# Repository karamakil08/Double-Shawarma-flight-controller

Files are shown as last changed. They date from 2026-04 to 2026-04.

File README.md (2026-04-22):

🚀 Double Shawarma: High-Performance Micro Drone
Double Shawarma is a custom-engineered, ultra-lightweight micro drone built on the ESP32-C3 architecture. Designed for agility and durability, this project pushes the limits of 1S-powered flight using 8.5mm coreless motors and a bespoke 3D-printed chassis optimized for maximum structural rigidity.

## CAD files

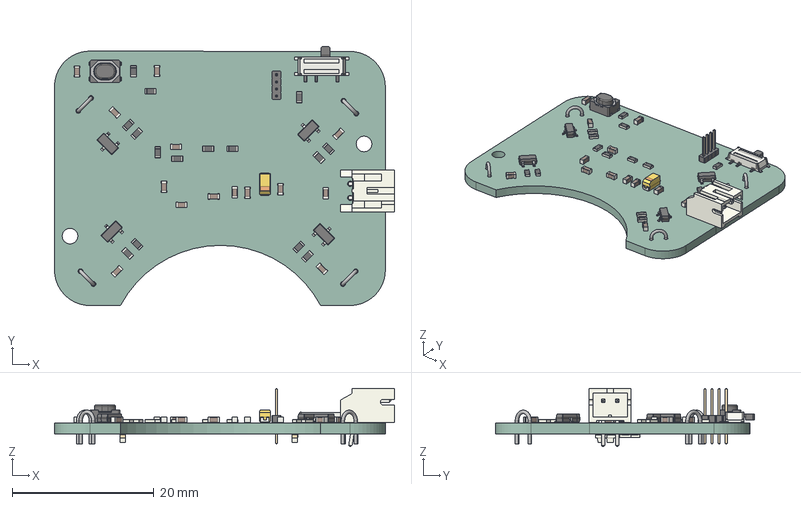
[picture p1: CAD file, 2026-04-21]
PCB/delikli.step
48.0 x 36.6 x 8.25 mm
R_0603_1608Metric x 17
JST_PH_S2B-PH-K_1x02_P2.00mm_Horizontal
SOT-23 x 4
SW_SPDT_PCM12
C_0603_1608Metric x 14
TestPoint_Bridge_Pitch2.54mm_Drill0.7mm x 4
SW_SPST_PTS810
CP_EIA-3216-18_Kemet-A
PinHeader_1x04_P1.00mm_Vertical
LED_0603_1608Metric x 2
Dobule shawarma PCB_PCB

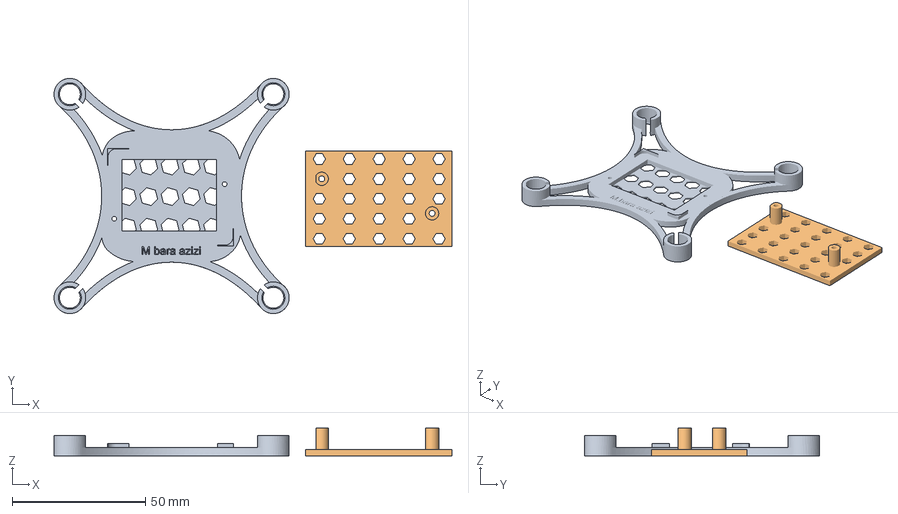
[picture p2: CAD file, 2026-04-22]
ready to print_1.3mf
149.6 x 88.4 x 10.4 mm

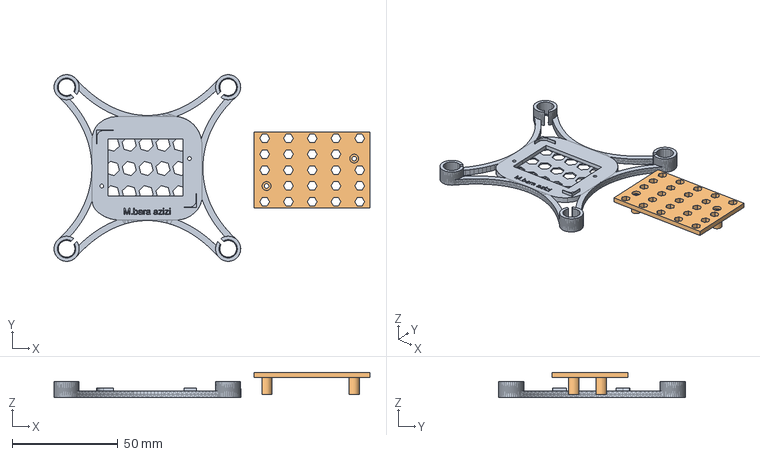
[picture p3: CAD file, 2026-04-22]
final_22_04.step
149.6 x 88.4 x 12.0 mm

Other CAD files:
FRAME.gcode.3mf

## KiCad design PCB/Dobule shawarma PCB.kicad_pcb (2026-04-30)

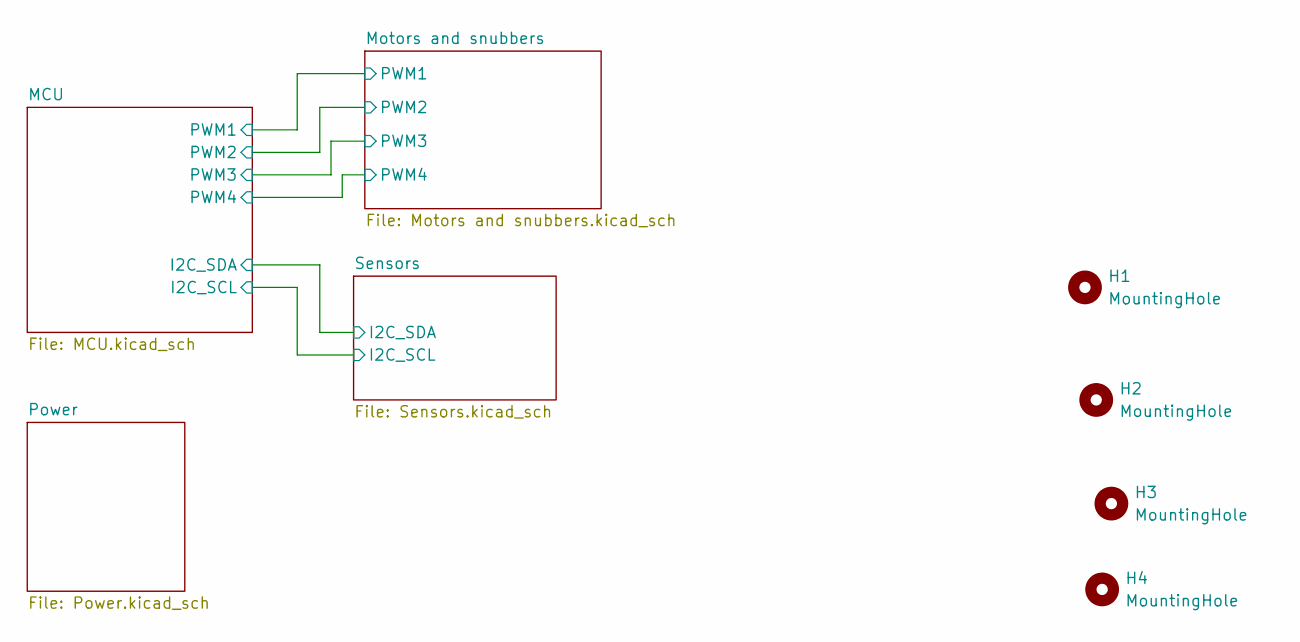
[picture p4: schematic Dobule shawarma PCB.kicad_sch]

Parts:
H1, H2, H3, H4: MountingHole; MountingHole_2.2mm_M2_Pad_Via

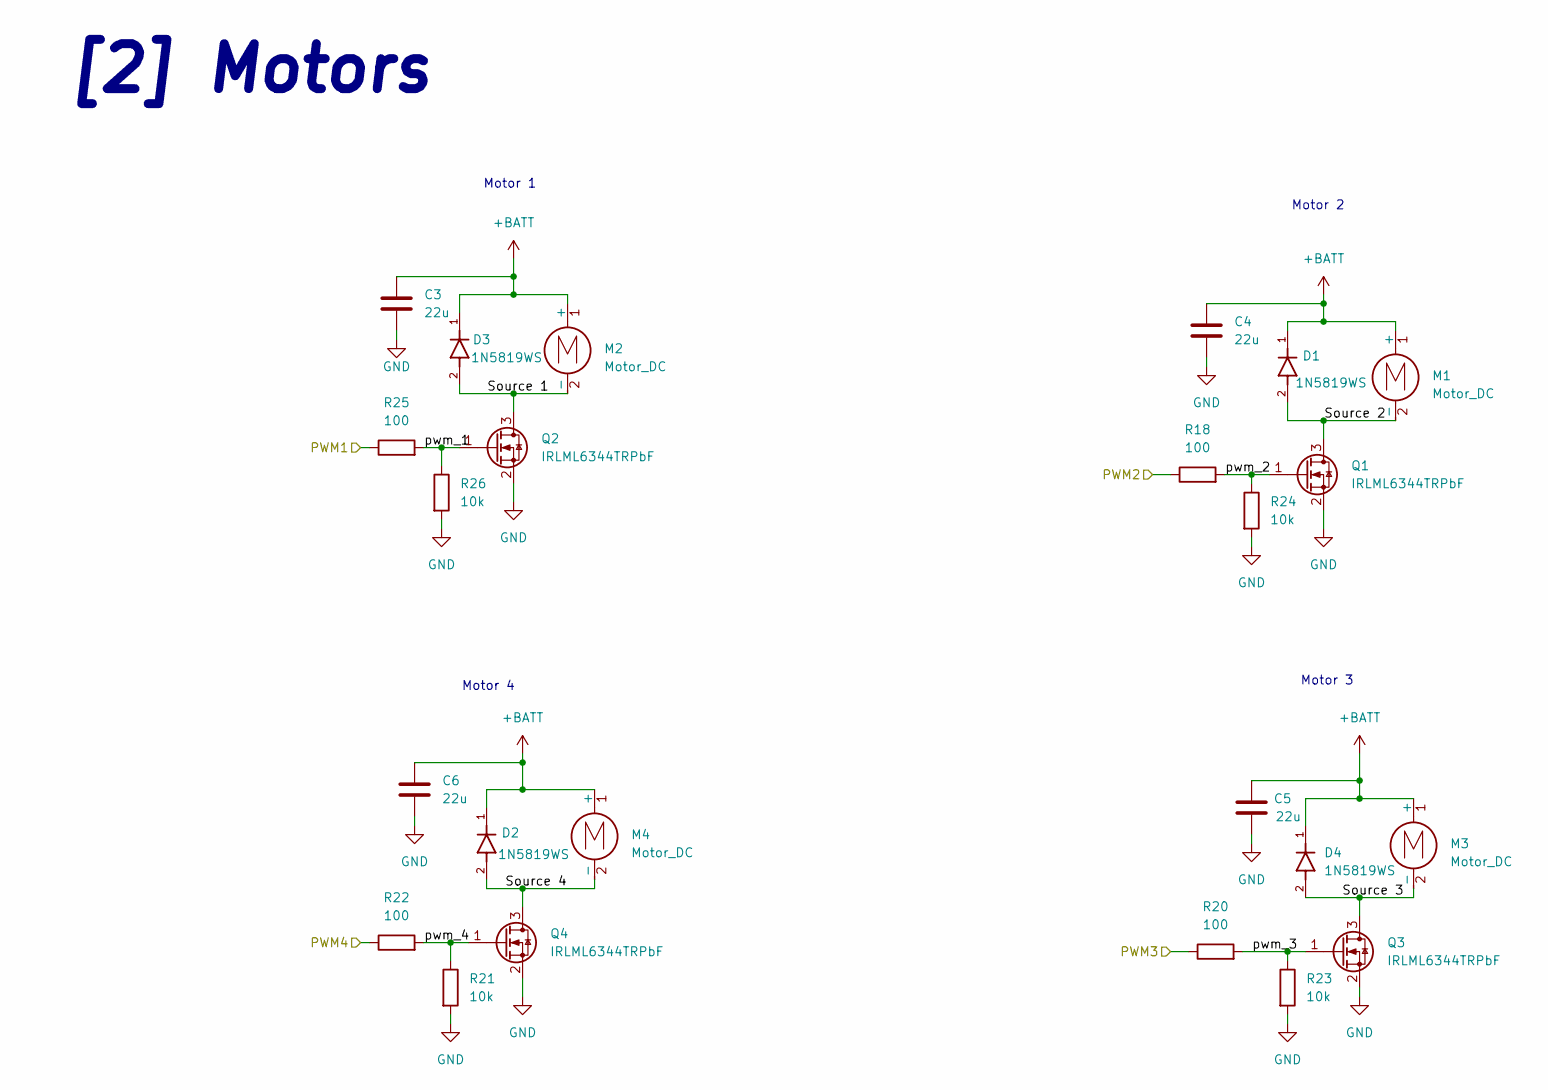
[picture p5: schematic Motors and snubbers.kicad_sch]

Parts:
C3, C4, C5, C6: 22u; C_0603_1608Metric_Pad1.08x0.95mm_HandSolder
D1, D2, D3, D4: 1N5819WS; CR_SOD323_MCC; PARTREV G
M1, M2, M3, M4: Motor_DC; TestPoint_Bridge_Pitch2.54mm_Drill0.7mm
Q1, Q2, Q3, Q4: IRLML6344TRPbF; SOT-23
R18, R20, R22, R25: 100; R_0603_1608Metric_Pad0.98x0.95mm_HandSolder
R21, R23, R24, R26: 10k; R_0603_1608Metric_Pad0.98x0.95mm_HandSolder

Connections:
+BATT: C3.2, C4.2, C5.2, C6.2, D1.1, D2.1, D3.1, D4.1, M1.1 (+), M2.1 (+), M3.1 (+), M4.1 (+); also elsewhere on the board
/MCU/PWM1: R25.1; also elsewhere on the board
/MCU/PWM2: R18.1; also elsewhere on the board
/MCU/PWM3: R20.1; also elsewhere on the board
/MCU/PWM4: R22.1; also elsewhere on the board
/Motors and snubbers/Source 1: D3.2, M2.2 (-), Q2.3 (D)
/Motors and snubbers/Source 2: D1.2, M1.2 (-), Q1.3 (D)
/Motors and snubbers/Source 3: D4.2, M3.2 (-), Q3.3 (D)
/Motors and snubbers/Source 4: D2.2, M4.2 (-), Q4.3 (D)
/Motors and snubbers/pwm_1: Q2.1 (G), R25.2, R26.1
/Motors and snubbers/pwm_2: Q1.1 (G), R18.2, R24.1
/Motors and snubbers/pwm_3: Q3.1 (G), R20.2, R23.1
/Motors and snubbers/pwm_4: Q4.1 (G), R21.1, R22.2
GND: C3.1, C4.1, C5.1, C6.1, Q1.2 (S), Q2.2 (S), Q3.2 (S), Q4.2 (S), R21.2, R23.2, R24.2, R26.2; also elsewhere on the board

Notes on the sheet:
Motor 3
Motor 2
Motor 1
[2] Motors
Motor 4

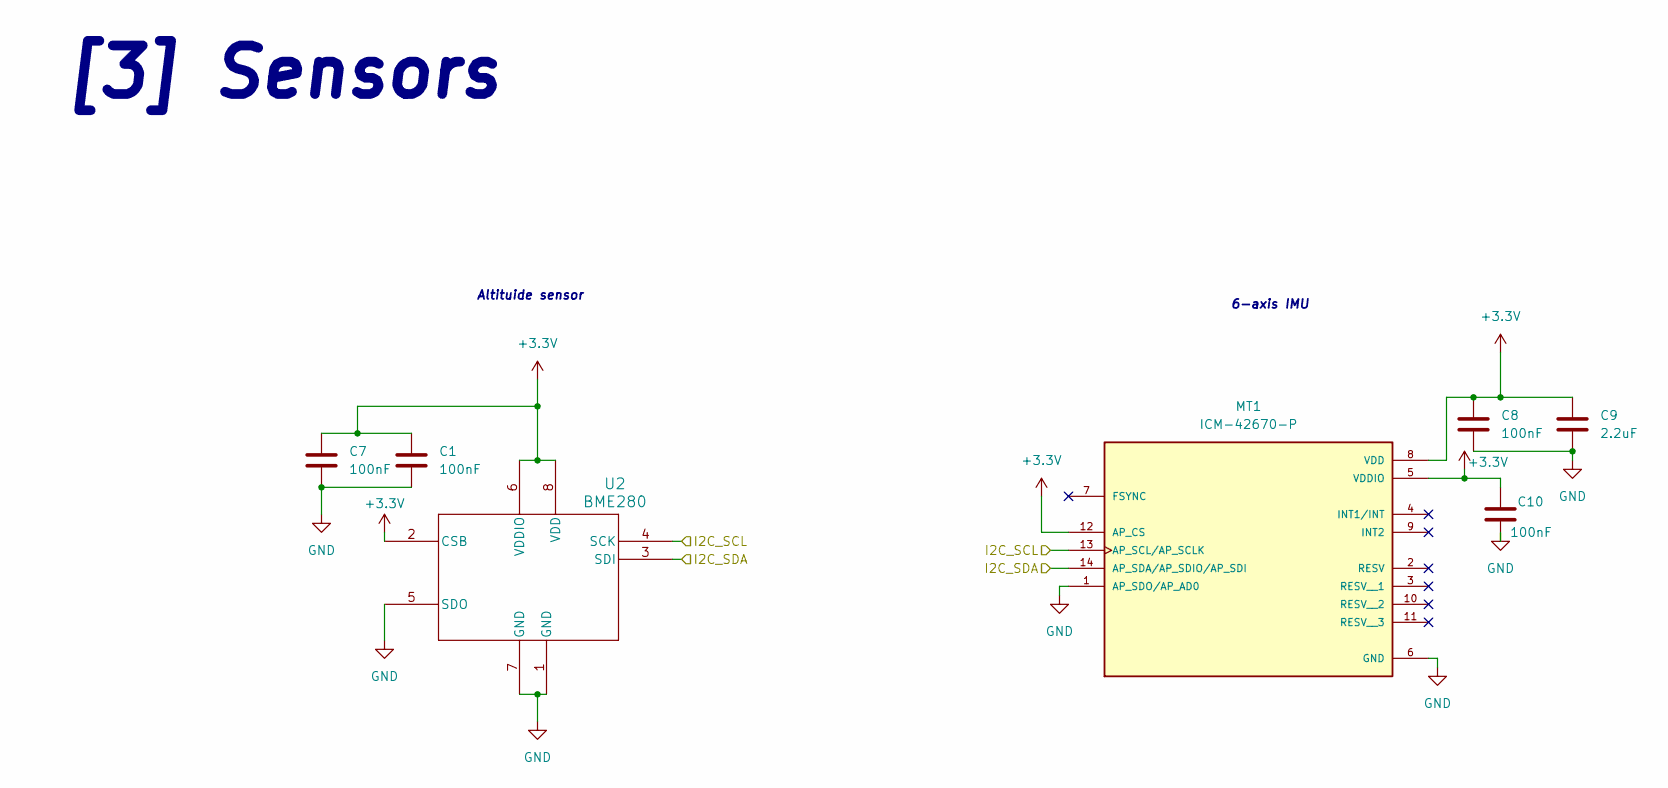
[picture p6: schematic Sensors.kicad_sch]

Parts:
C1, C7, C8, C10: 100nF; C_0603_1608Metric_Pad1.08x0.95mm_HandSolder
C9: 2.2uF; C_0603_1608Metric_Pad1.08x0.95mm_HandSolder
MT1: ICM-42670-P; XDCR_ICM-42670-P; PARTREV 1.1
U2: BME280; DFN8_0p65_2p5SQ_BOS

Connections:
+3.3V: C1.1, C7.1, C8.1, C9.1, C10.1, MT1.5 (VDDIO), MT1.8 (VDD), MT1.12 (AP_CS), U2.2 (CSB), U2.6 (VDDIO), U2.8 (VDD); also elsewhere on the board
/MCU/I2C_SCL: MT1.13 (AP_SCL/AP_SCLK), U2.4 (SCK); also elsewhere on the board
/MCU/I2C_SDA: MT1.14 (AP_SDA/AP_SDIO/AP_SDI), U2.3 (SDI); also elsewhere on the board
GND: C1.2, C7.2, C8.2, C9.2, C10.2, MT1.1 (AP_SDO/AP_AD0), MT1.6 (GND), U2.1 (GND), U2.5 (SDO), U2.7 (GND); also elsewhere on the board

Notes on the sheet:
6-axis IMU
Altituide sensor
[3] Sensors

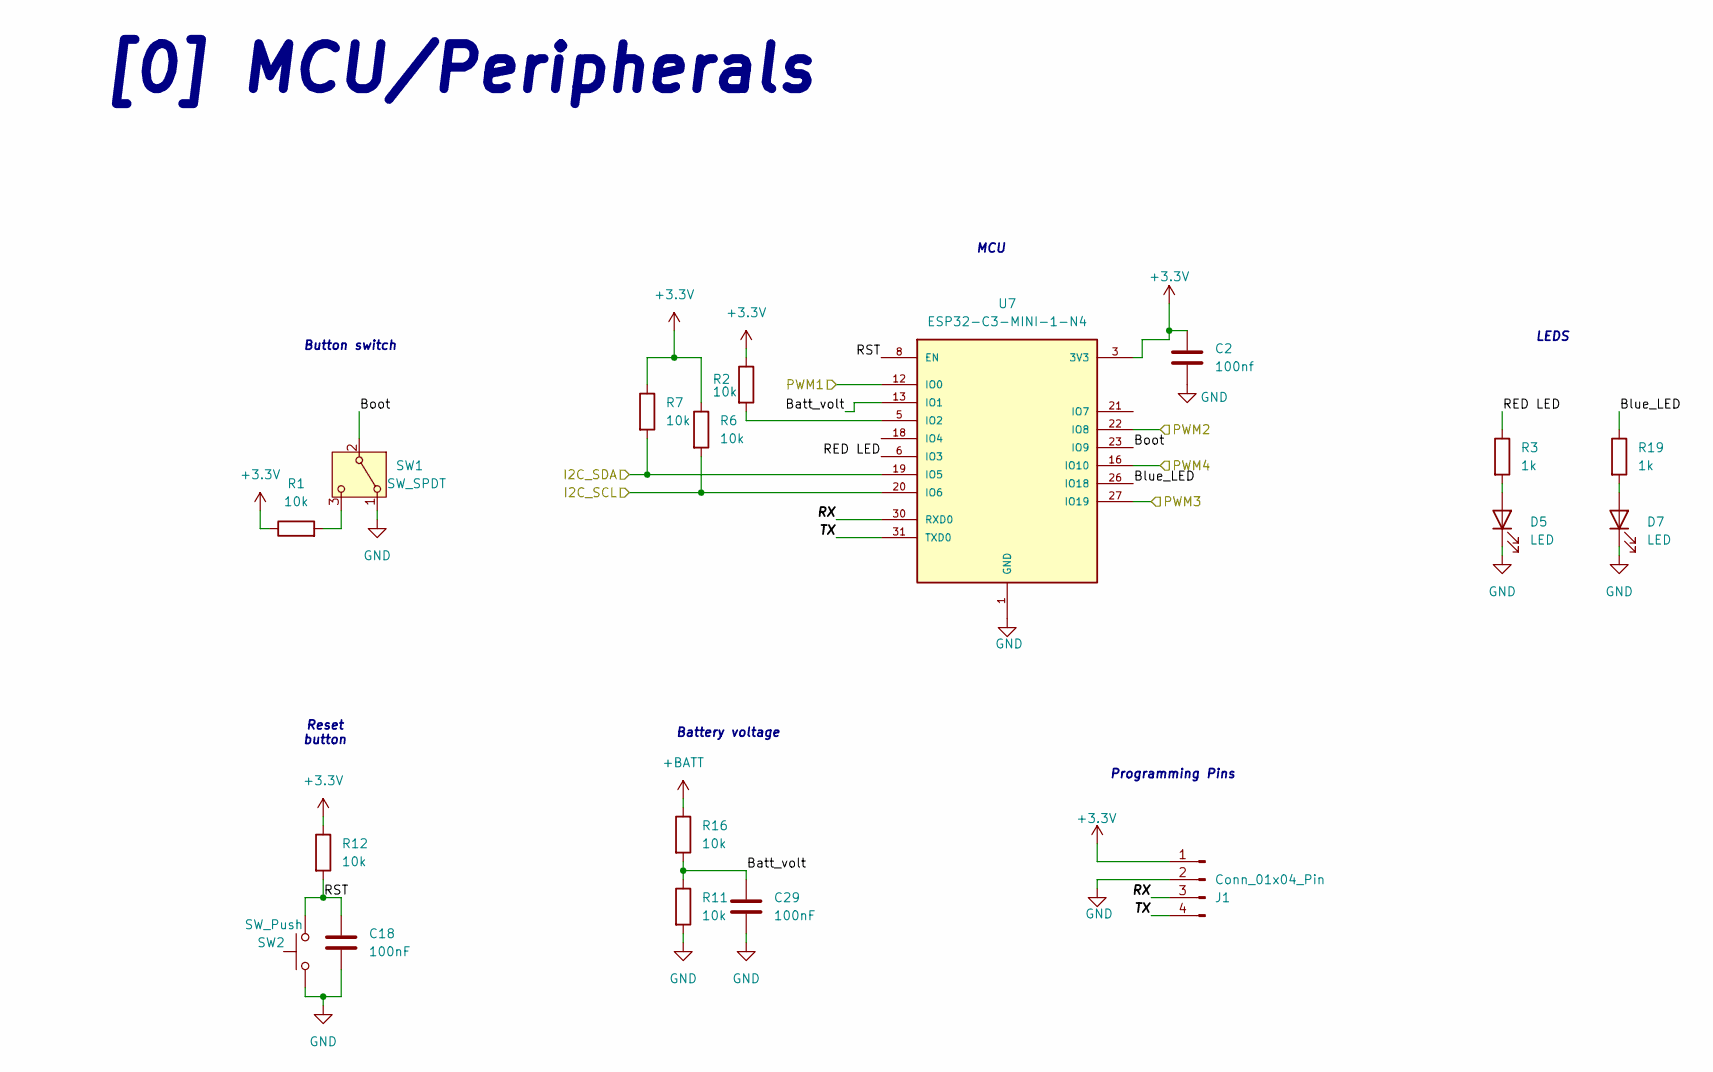
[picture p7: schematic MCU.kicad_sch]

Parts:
C2: 100nf; C_0603_1608Metric_Pad1.08x0.95mm_HandSolder
C18, C29: 100nF; C_0603_1608Metric_Pad1.08x0.95mm_HandSolder
D5, D7: LED; LED_0603_1608Metric_Pad1.05x0.95mm_HandSolder
J1: Conn_01x04_Pin; PinHeader_1x04_P1.00mm_Vertical
R1, R2: 10k; R_0603_1608Metric
R3, R19: 1k; R_0603_1608Metric_Pad0.98x0.95mm_HandSolder
R6, R7, R11, R12, R16: 10k; R_0603_1608Metric_Pad0.98x0.95mm_HandSolder
SW1: SW_SPDT; SW_SPDT_PCM12
SW2: SW_Push; SW_SPST_PTS810
U7: ESP32-C3-MINI-1-N4; XCVR_ESP32-C3-MINI-1-N4; PARTREV v1.0

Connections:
+3.3V: C2.1, J1.1, R1.1, R2.1, R6.1, R7.1, R12.1, U7.3 (3V3); also elsewhere on the board
+BATT: R16.1; also elsewhere on the board
/MCU/Batt_volt: C29.1, R11.1, R16.2, U7.13 (IO1)
/MCU/Blue_LED: R19.1, U7.26 (IO18)
/MCU/Boot: SW1.2 (B), U7.23 (IO9)
/MCU/I2C_SCL: R6.2, U7.20 (IO6); also elsewhere on the board
/MCU/I2C_SDA: R7.2, U7.19 (IO5); also elsewhere on the board
/MCU/PWM1: U7.12 (IO0); also elsewhere on the board
/MCU/PWM2: U7.22 (IO8); also elsewhere on the board
/MCU/PWM3: U7.27 (IO19); also elsewhere on the board
/MCU/PWM4: U7.16 (IO10); also elsewhere on the board
/MCU/RED LED: R3.1, U7.6 (IO3)
/MCU/RST: C18.1, R12.2, SW2.2, U7.8 (EN)
/MCU/RX: J1.3, U7.30 (RXD0)
/MCU/TX: J1.4, U7.31 (TXD0)
GND: C2.2, C18.2, C29.2, D5.1 (K), D7.1 (K), J1.2, R11.2, SW1.1 (A), SW2.1, U7.1 (GND), U7.2 (GND__1), U7.11 (GND__2), U7.14 (GND__3), U7.36 (GND__4), U7.37 (GND__5), U7.38 (GND__6), U7.39 (GND__7), U7.40 (GND__8), U7.41 (GND__9), U7.42 (GND__10), U7.43 (GND__11), U7.44 (GND__12), U7.45 (GND__13), U7.46 (GND__14), U7.47 (GND__15), U7.48 (GND__16), U7.49_1 (GND__17), U7.49_2 (GND__18), U7.49_3 (GND__19), U7.49_4 (GND__20), U7.49_5 (GND__21), U7.49_6 (GND__22), U7.49_7 (GND__23), U7.49_8 (GND__24), U7.49_9 (GND__25), U7.50 (GND__26), U7.51 (GND__27), U7.52 (GND__28), U7.53 (GND__29); also elsewhere on the board
unnamed: D5.2 (A), R3.2
unnamed: D7.2 (A), R19.2
unnamed: R1.2, SW1.3 (C)
unnamed: R2.2, U7.5 (IO2)

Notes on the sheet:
MCU
LEDS
Reset button
[0] MCU/Peripherals
Button switch
Programming Pins
Battery voltage

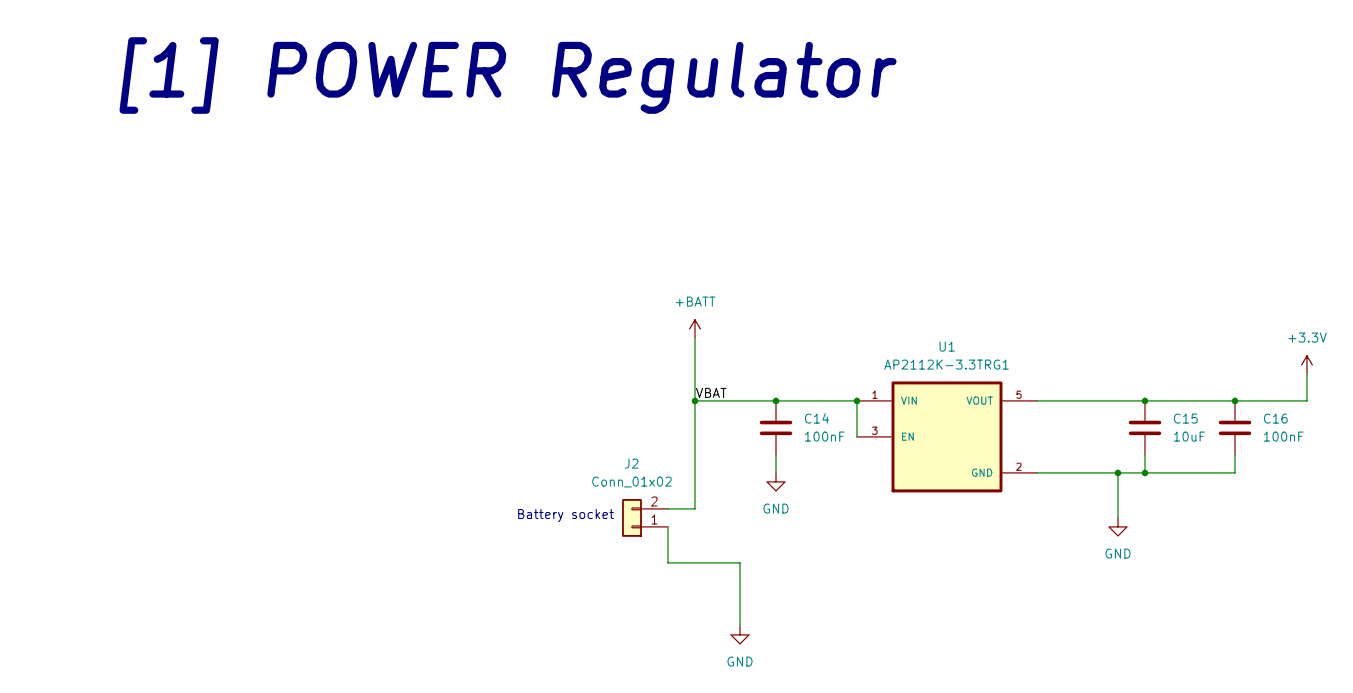
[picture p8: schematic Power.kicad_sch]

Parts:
C14, C16: 100nF; C_0603_1608Metric_Pad1.08x0.95mm_HandSolder
C15: 10uF; CP_EIA-3216-18_Kemet-A_HandSolder
J2: Conn_01x02; JST_PH_S2B-PH-K_1x02_P2.00mm_Horizontal
U1: AP2112K-3.3TRG1; SOT95P285X140-5N; PARTREV 2-2

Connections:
+3.3V: C15.1, C16.1, U1.5 (VOUT); also elsewhere on the board
+BATT: C14.1, J2.2, U1.1 (VIN), U1.3 (EN); also elsewhere on the board
GND: C14.2, C15.2, C16.2, J2.1, U1.2 (GND); also elsewhere on the board

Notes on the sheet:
[1] POWER Regulator
Battery socket

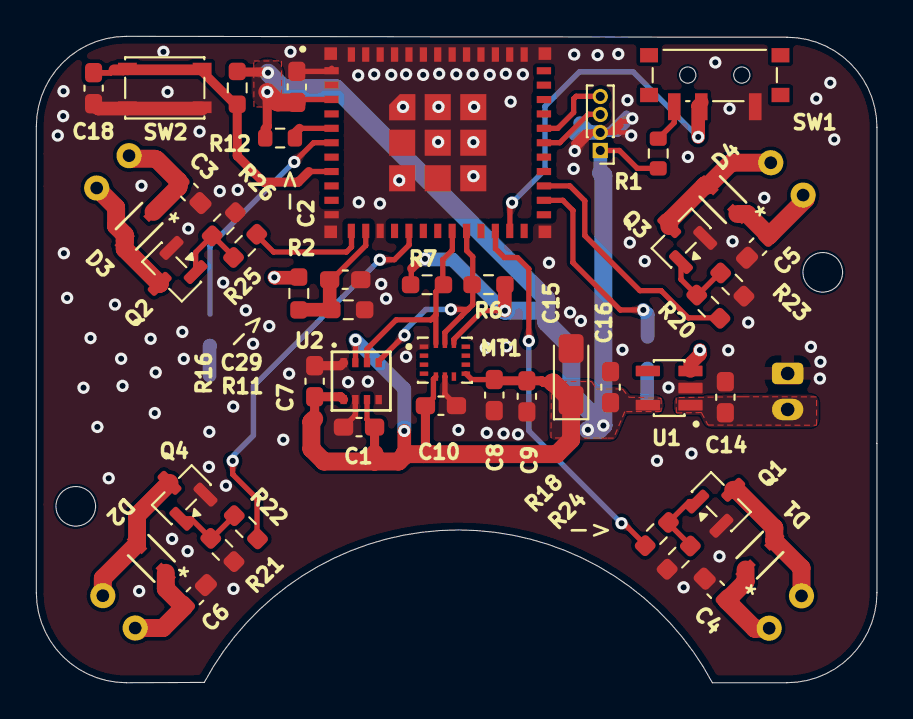
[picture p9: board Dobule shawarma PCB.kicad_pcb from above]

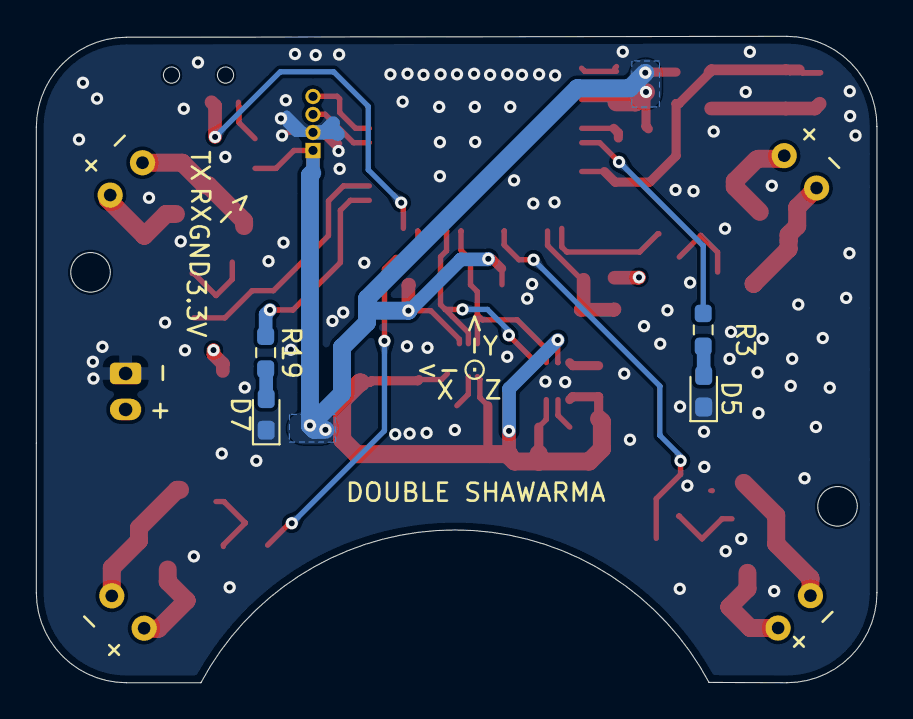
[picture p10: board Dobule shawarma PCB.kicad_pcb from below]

Board: 4 copper layers, 46.7 x 35.9 mm, 54 parts (4 on the bottom side), 28 nets.

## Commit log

2026-04-21 Final: Dobule Shawarma PCB v1 ve 0.143mm sasi hazir
    [Dobule shawarma PCB-B_Mask.gbr, Dobule shawarma PCB-B_Paste.gbr, Dobule shawarma PCB-B_Silkscreen.gbr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]
2026-04-21 Final: Organized into Hardware, Production and Chassis folders
    [Dobule shawarma PCB.kicad_pcb, Dobule shawarma PCB.kicad_sch, MCU.kicad_sch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]
2026-04-30 Bak bu harbi son olsun yeter amk
    [Dobule shawarma PCB.kicad_pcb, Dobule shawarma PCB.kicad_sch, MCU.kicad_sch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]
2026-04-30 Bu son olsun dostum
    [Dobule shawarma PCB.kicad_pcb, Dobule shawarma PCB.kicad_sch, MCU.kicad_sch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]
